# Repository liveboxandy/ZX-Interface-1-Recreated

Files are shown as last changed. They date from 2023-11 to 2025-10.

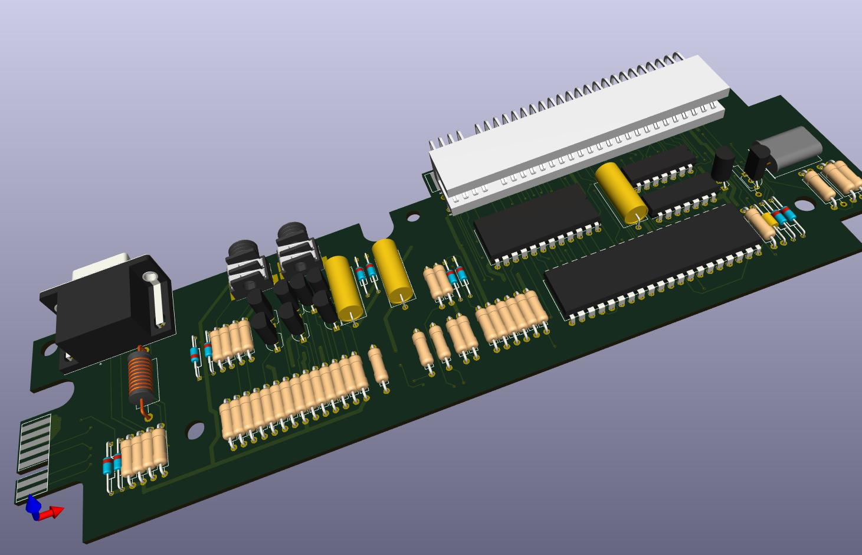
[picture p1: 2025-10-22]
Interface 1 Recreated.jpg

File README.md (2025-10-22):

# ZX-Interface-1-Recreated
Sinclair ZX Interface 1 recreated with the orignal Sinclair Routing

This is Kicad 9 project of the Sinclair ZX Interface 1 that uses the same routing and PCB dimensions as the orignal.
A raw board was scanned and the top and bottom side images were imported into Kicad. This gave the board outline 
along with the position of components and the track layout.
The schematic available from the Service Guide was then redrawn in Kicad and used to recreate the PCB and to verify that the routing was correct.

The Bill of Materials from the Service Guide was used to select suitable footprints. Some parts were obsolete and could not be located and so suitable repalcements were used.

Q11 does not have a place on the Sinclair PCB as it was an afterthought. To stop Kicad moaning I have placed it within the footprint of R2 which is not fitted.

This is the result of that exercise.

The files 'Interface 1 Recreated with images.*' when combined will produce an Interface 1 Recreated.kicad_pcb file that includes the top/bottom images. It appears that a 75MB is too be for uploading so I split it into 20MB chunks.

Sometimes Kicad complains that there is an issue with the edge.cuts file. Running DRC will show what it doesn't like and it's easy to fix so that the board outline is a closed shape.

The bom/ibom.html is an interactive BOM that will show component position as well as routing in a web browser.

Have fun.

Comments - Good Bad or totally indifferent on https://www.facebook.com/groups/zxspa/

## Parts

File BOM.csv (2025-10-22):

Reference | Value | Datasheet | Footprint | Qty | DNP
C1,C2,C6 | 47uF 16V | ~ | Capacitor_THT:C_Axial_L17.0mm_D6.5mm_P20.00mm_Horizontal | 3
C3 | 100pF | ~ | Spectrum:Capacitor Ceramic | 1
C4 | 22pF | ~ | Spectrum:Capacitor Ceramic | 1
C5 | 47nF | ~ | Capacitor_THT:C_Axial_L3.8mm_D2.6mm_P12.50mm_Horizontal | 1
C7,C8 | 330pF | ~ | Spectrum:Capacitor Ceramic | 2
D1,D2 | BA157 | https://www.vishay.com/docs/88536/ba157.pdf | Spectrum:Diode 1N | 2
D3,D4,D9,D10,D11 | 1N4148 | https://assets.nexperia.com/documents/data-sheet/1N4148_1N4448.pdf | Spectrum:Diode 1N | 5
D6,D7,D8 | BZX79CV4V3 | ~ | Spectrum:Diode 1N | 3
L1 | 22uH 0.41A | ~ | Inductor_THT:L_Axial_L12.8mm_D5.8mm_P20.32mm_Horizontal_Fastron_HBCC | 1
NoFit1 | 0R | ~ | Spectrum:Resistor_0.25W | 1 | DNP
Q1,Q2,Q4,Q5 | BC213C | ~ | Package_TO_SOT_THT:TO-92L_Inline_Wide | 4
Q3,Q6,Q9 | BC184C | ~ | Package_TO_SOT_THT:TO-92L_Inline_Wide | 3
Q10,Q11 | BC183 | ~ | Package_TO_SOT_THT:TO-92L_Inline_Wide | 2
R1,R3,R5,R11,R14,R19,R31 | 1K0 | -- mixed values -- | -- mixed values -- | 7
R2 | NoFit | ~ | Spectrum:Resistor_0.25W | 1 | DNP
R4,R6,R8,R16 | 3K9 | ~ | Spectrum:Resistor_0.25W | 4
R7 | 47R | ~ | Spectrum:Resistor_0.25W | 1
R9,R21,R25,R26,R27,R33,R36 | 10K | ~ | Spectrum:Resistor_0.25W | 7
R10 | 2K2 | ~ | Spectrum:Resistor_0.25W | 1
R12,R15 | 12K | ~ | Spectrum:Resistor_0.25W | 2
R13,R18,R32 | 680R | ~ | Spectrum:Resistor_0.25W | 3
R17,R20 | 2K7 | ~ | Spectrum:Resistor_0.25W | 2
R22,R23,R34 | 330R | ~ | Spectrum:Resistor_0.25W | 3
R24 | 4K7 | ~ | Spectrum:Resistor_0.25W | 1
R28,R29 | 6K8 | ~ | Spectrum:Resistor_0.25W | 2
R30 | 270R | ~ | Spectrum:Resistor_0.25W | 1
R35 | 47K | ~ | Spectrum:Resistor_0.25W | 1
SK1 | DE9_Receptacle | ~ | Connector_Dsub:DSUB-9_Female_Horizontal_P2.77x2.84mm_EdgePinOffset14.56mm_Housed_MountingHolesOffset15.98mm | 1
SK2,SK3 | Network | ~ | ZX Spectrum 3.5mm:ZX Spectrum 3.5mm Skt | 2
SK4 | Microdrive | ~ | ZX Bits:ZX_MD_Edge_Connector | 1
SK5 | ZX Spectrum |  | ZX Bits:Spectrum_Edge_Connector | 1
SK6 | ZX Expansion |  | ZX Bits:ZX_Bus_Edge_Connector | 1
U1 | LA15-302 | LA 15-302 Custom ULA | Package_DIP:DIP-40_W15.24mm | 1
U2 | TMS4764 |  | Package_DIP:DIP-24_W15.24mm | 1
U3 | 74LS260 |  | Package_DIP:DIP-14_W7.62mm | 1
U4 | 74HC04 | https://assets.nexperia.com/documents/data-sheet/74HC_HCT04.pdf | Package_DIP:DIP-14_W7.62mm | 1
X1 | 8Mhz | ~ | Crystal:Crystal_HC18-U_Horizontal | 1

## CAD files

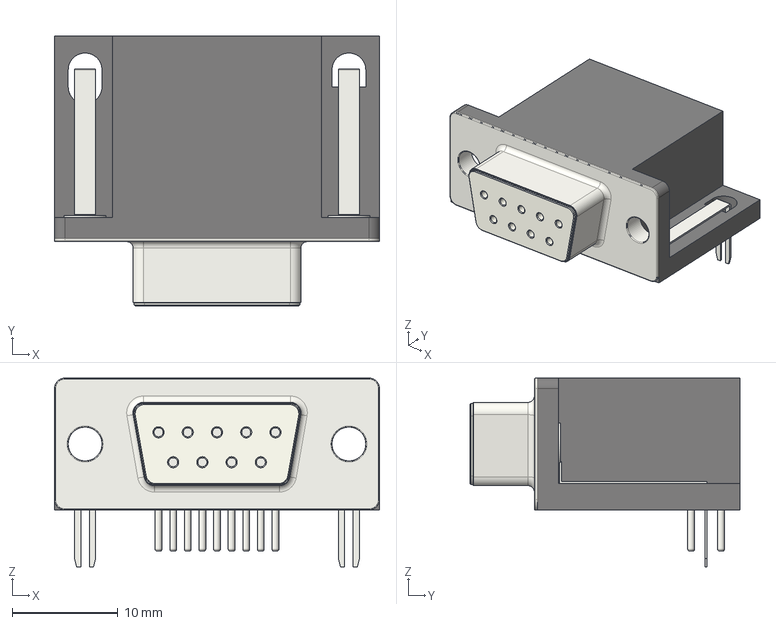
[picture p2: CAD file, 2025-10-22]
Step/DSUB-9_Female_Horizontal_P2.77x2.84mm_EdgePinOffset14.56mm_Housed_MountingHolesOffset15.98mm.step
30.8 x 25.6 x 17.9 mm

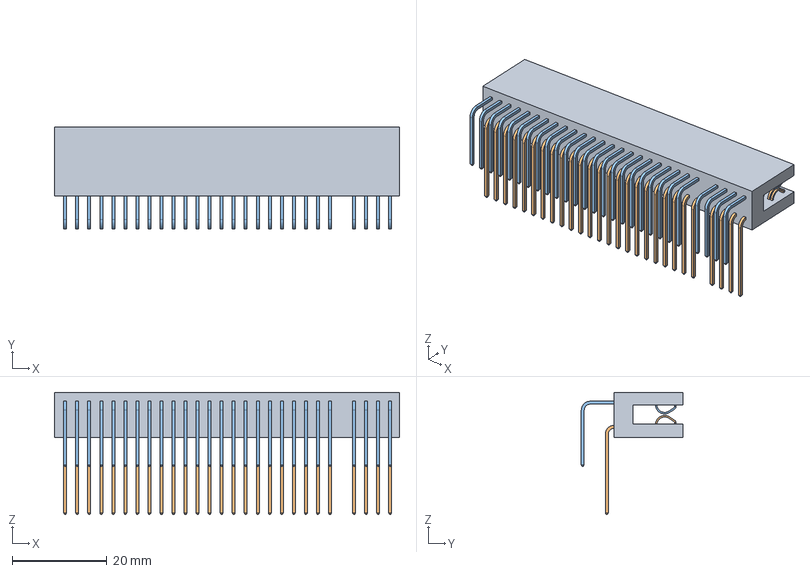
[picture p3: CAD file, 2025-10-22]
Step/28+28 RA ZX Spectrum.step
72.8 x 21.4 x 25.8 mm
345-292-001_558 559 Tail - 1
345-292-001_558 Tail - 2
345-292-001_558 559 Tail - 002
345-292-001_558 559 Tail - 003
345-292-001_558 Tail - 003
345-292-001_558 Tail - 004
345-292-001_558 559 Tail - 004
345-292-001_558 559 Tail - 005
345-292-001_558 Tail - 005
345-292-001_558 Tail - 006
345-292-001_558 559 Tail - 006
345-292-001_558 Tail - 007
345-292-001_558 559 Tail - 007
345-292-001_558 Tail - 008
345-292-001_558 559 Tail - 008
345-292-001_558 Tail - 009
345-292-001_558 559 Tail - 009
345-292-001_558 Tail - 010
345-292-001_558 559 Tail - 010
345-292-001_558 Tail - 011
345-292-001_558 559 Tail - 011
345-292-001_558 Tail - 012
345-292-001_558 559 Tail - 012
345-292-001_558 Tail - 013
345-292-001_558 559 Tail - 013
345-292-001_558 Tail - 014
345-292-001_558 559 Tail - 014
345-292-001_558 Tail - 015
345-292-001_558 559 Tail - 015
345-292-001_558 Tail - 016
345-292-001_558 559 Tail - 016
345-292-001_558 Tail - 017
345-292-001_558 559 Tail - 017
345-292-001_558 Tail - 018
345-292-001_558 559 Tail - 018
345-292-001_558 Tail - 019
345-292-001_558 559 Tail - 019
345-292-001_558 Tail - 020
345-292-001_558 559 Tail - 020
345-292-001_558 Tail - 021
345-292-001_558 559 Tail - 021
345-292-001_558 Tail - 022
345-292-001_558 559 Tail - 022
345-292-001_558 Tail - 023
345-292-001_558 559 Tail - 023
345-292-001_558 Tail - 024
345-292-001_558 559 Tail - 025
345-292-001_558 Tail - 026
345-292-001_558 559 Tail - 026
345-292-001_558 Tail - 027
345-292-001_558 559 Tail - 027
345-292-001_558 Tail - 028
345-292-001_558 559 Tail - 028
345-292-001_558 Tail - 029

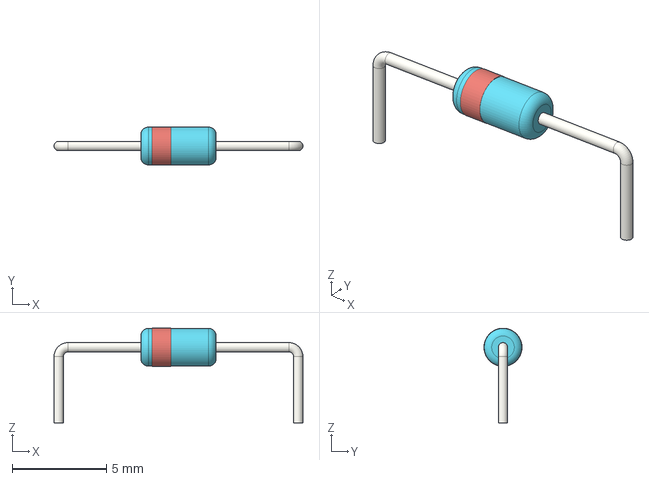
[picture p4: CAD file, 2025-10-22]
Step/D_DO-35_SOD27_P12.70mm_Horizontal.step
13.2 x 2.02 x 5.01 mm

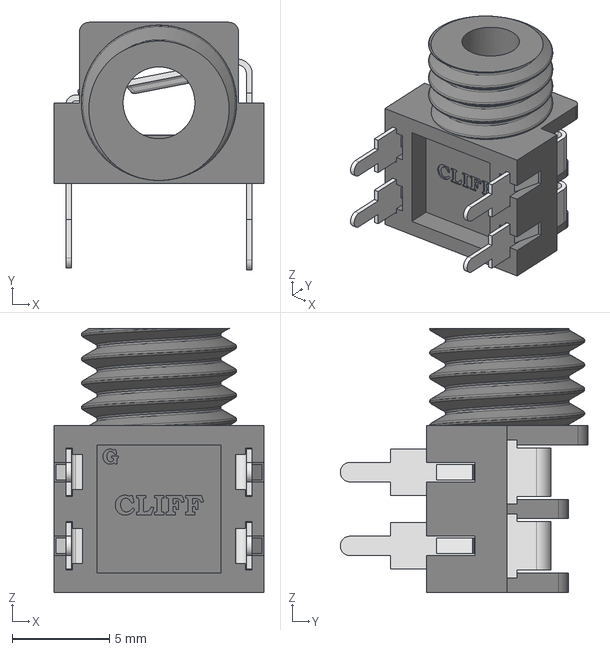
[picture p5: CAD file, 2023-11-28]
Step/FCR1281 S6A 6mm.stp
10.8 x 12.8 x 13.6 mm

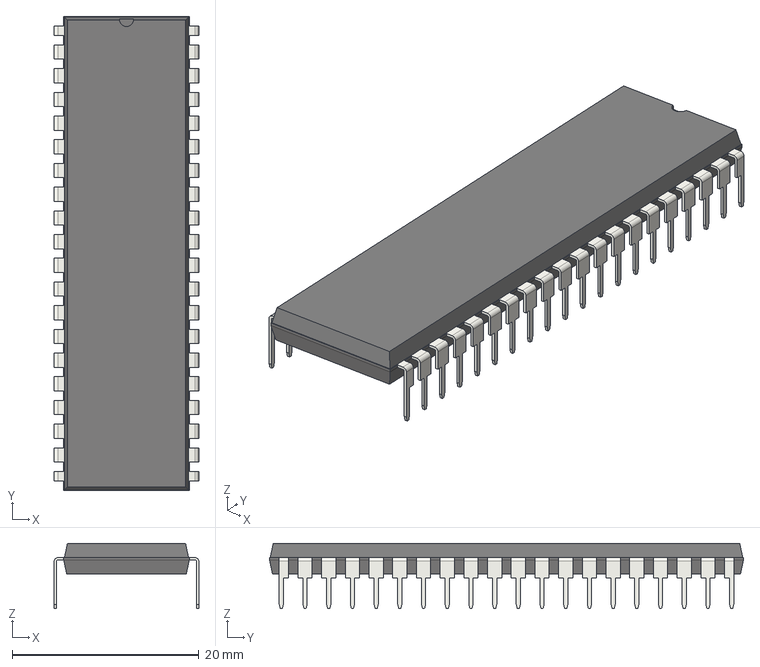
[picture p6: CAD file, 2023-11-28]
Step/DIP-40_W15.24mm.step
15.5 x 50.8 x 6.98 mm

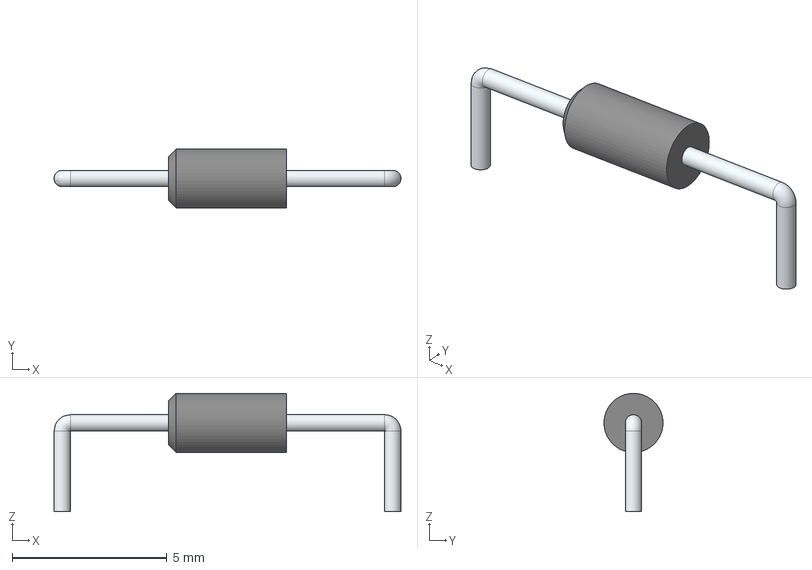
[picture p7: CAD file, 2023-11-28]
Step/1N4148.stp
11.2 x 1.91 x 3.82 mm

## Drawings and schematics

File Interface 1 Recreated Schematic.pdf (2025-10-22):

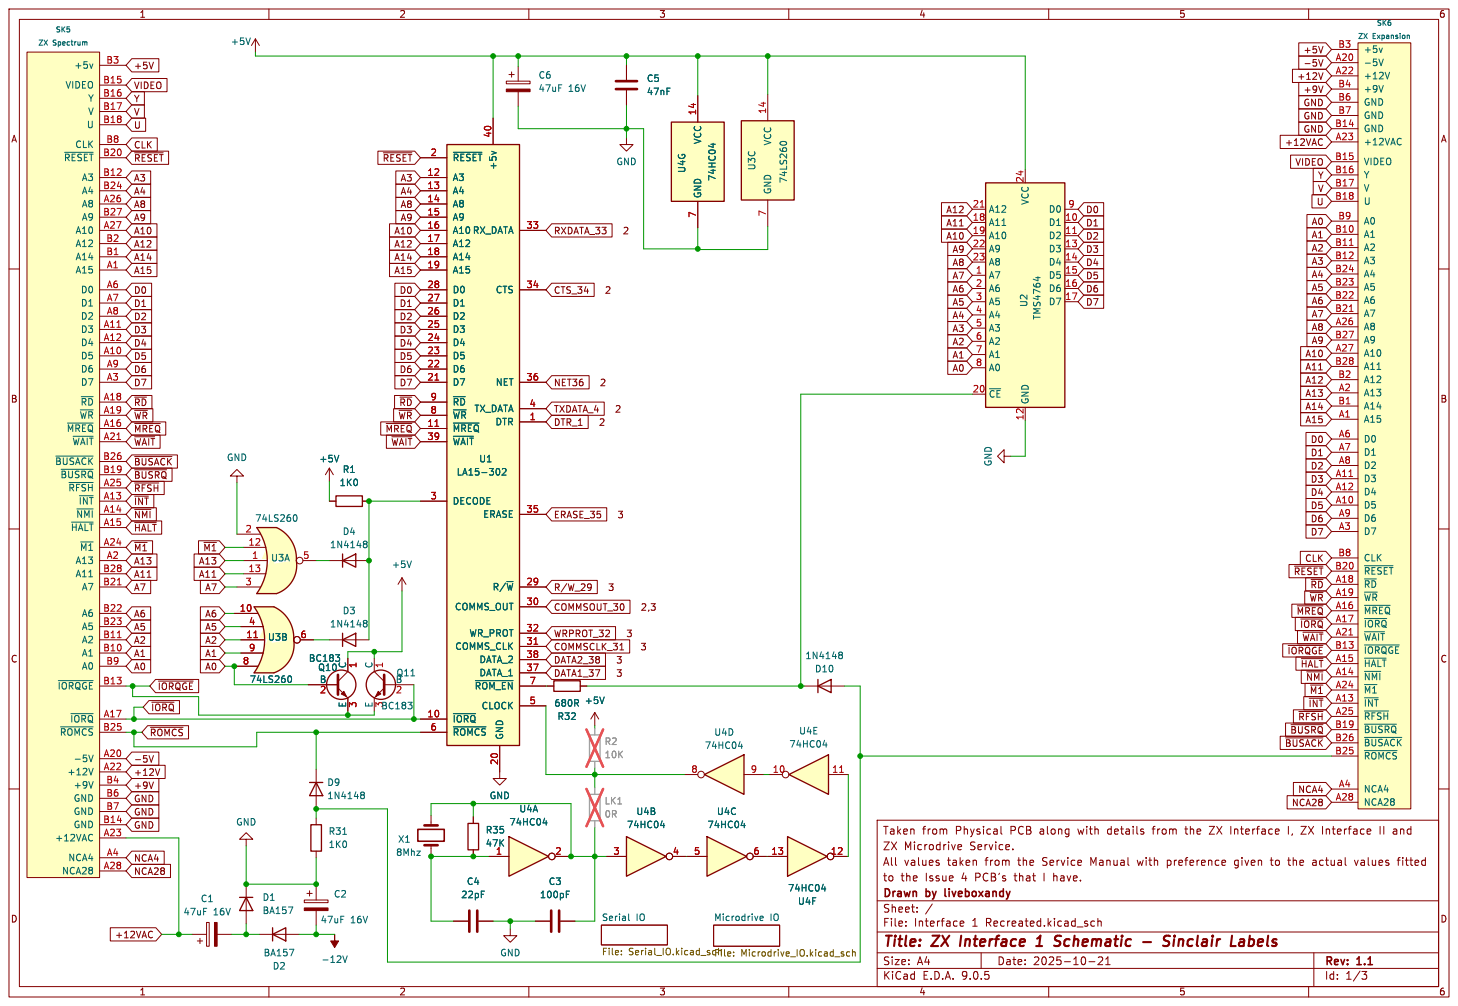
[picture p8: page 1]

Id: 1/3 Title: ZX Interface 1 Schematic - Sinclair Labels

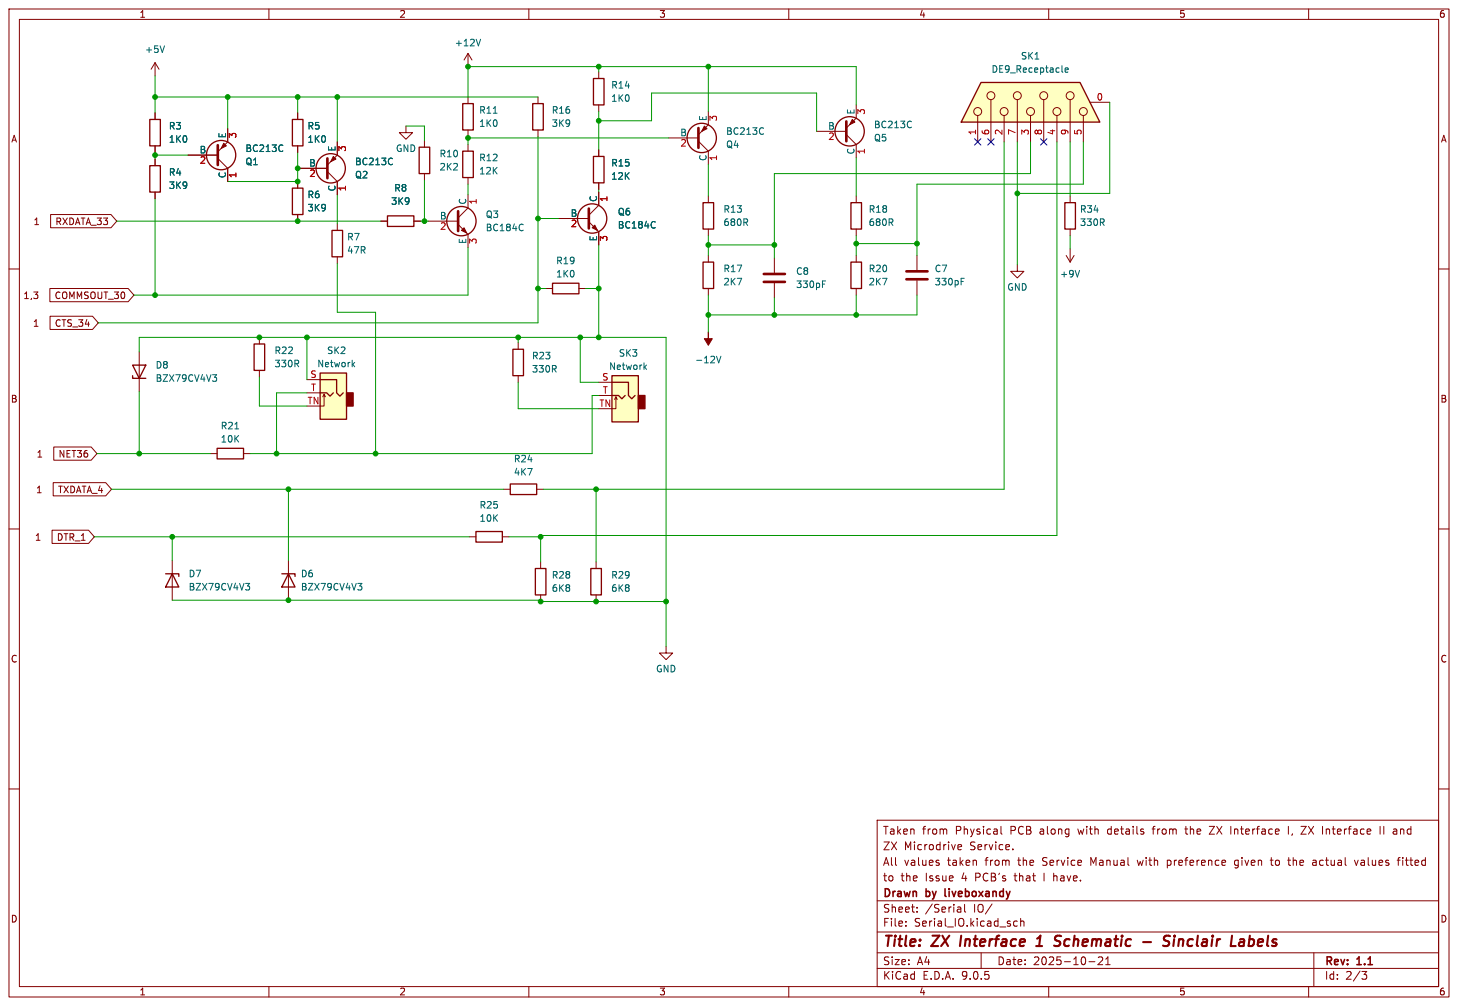
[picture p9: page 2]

Id: 2/3 Title: ZX Interface 1 Schematic - Sinclair Labels

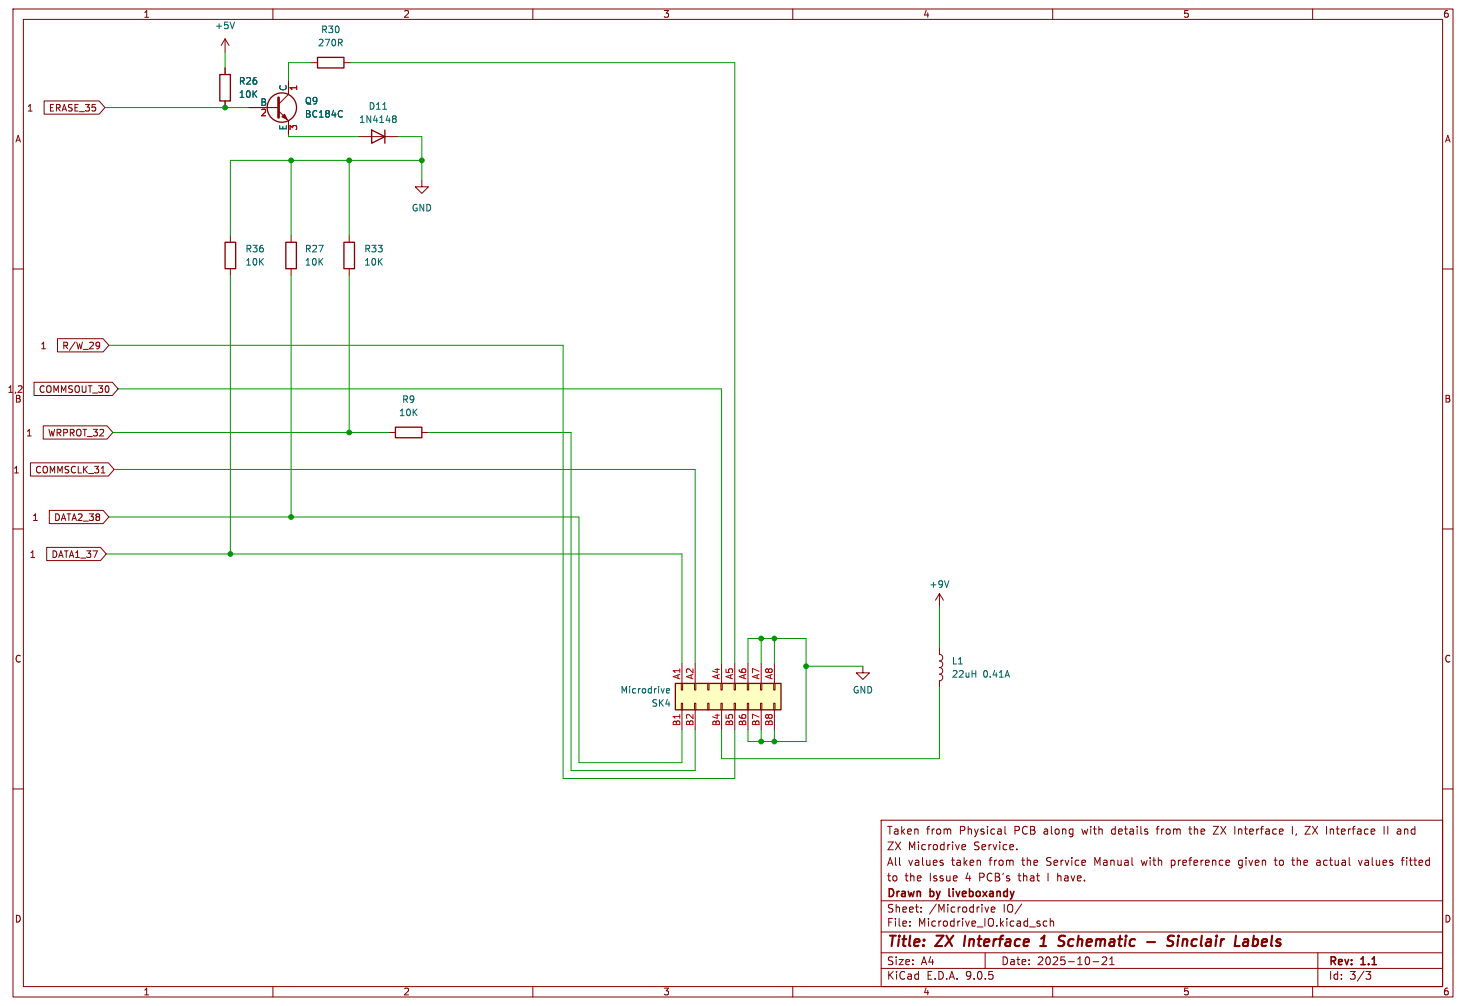
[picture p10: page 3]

Id: 3/3 Title: ZX Interface 1 Schematic - Sinclair Labels

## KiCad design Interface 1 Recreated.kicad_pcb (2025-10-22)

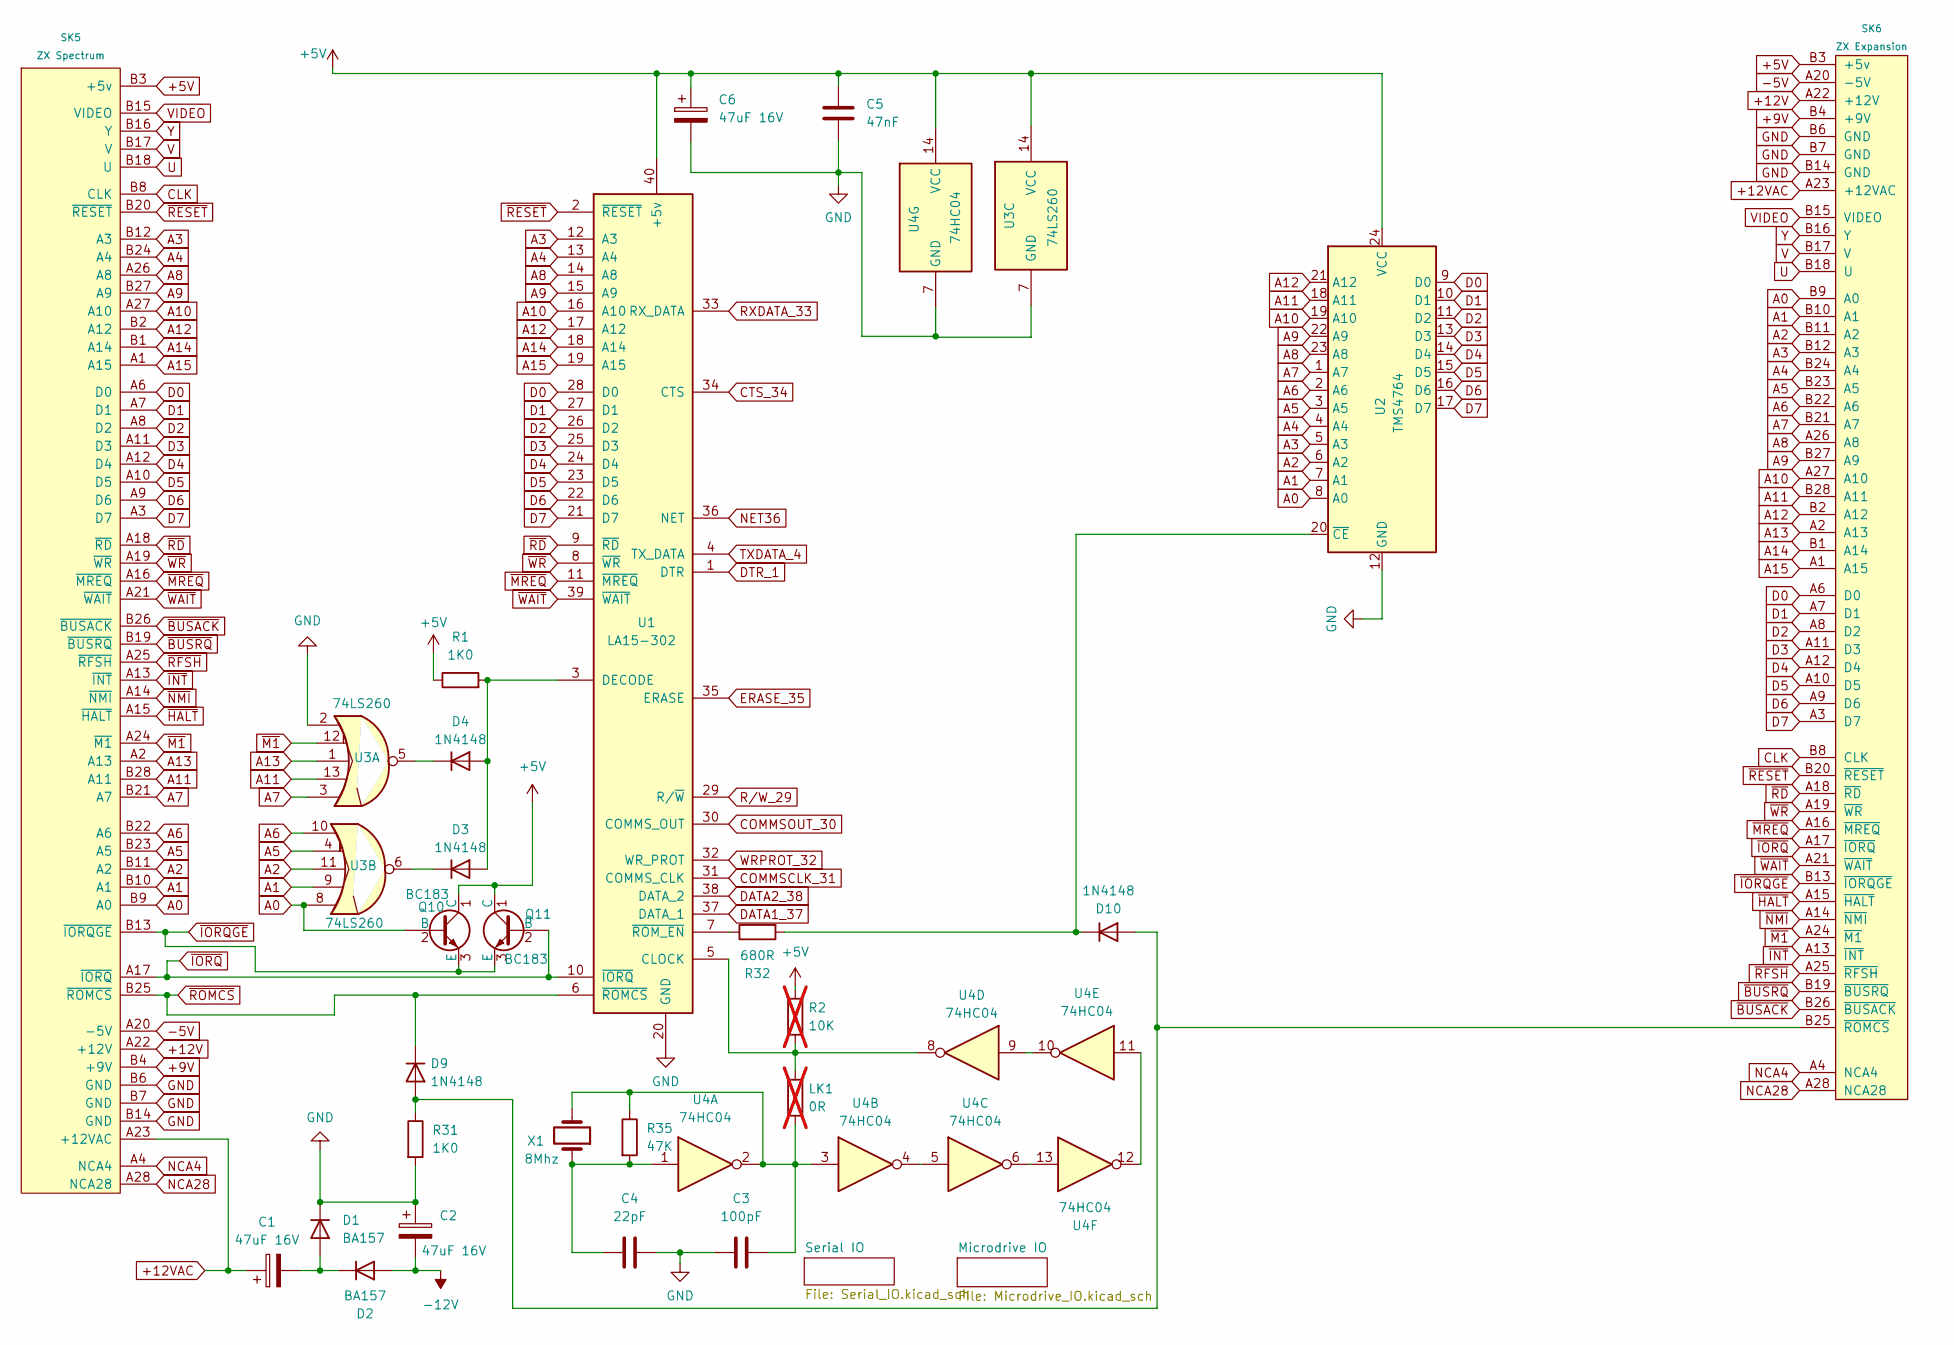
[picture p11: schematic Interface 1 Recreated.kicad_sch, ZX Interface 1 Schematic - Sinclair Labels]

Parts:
C1, C2, C6: 47uF 16V; C_Axial_L17.0mm_D6.5mm_P20.00mm_Horizontal
C3: 100pF; Capacitor Ceramic
C4: 22pF; Capacitor Ceramic
C5: 47nF; C_Axial_L3.8mm_D2.6mm_P12.50mm_Horizontal
D1, D2: BA157; Diode 1N
D3, D4, D9, D10: 1N4148; Diode 1N
LK1: 0R; Resistor_0.25W; not fitted
Q10, Q11: BC183; TO-92L_Inline_Wide
R1, R31: 1K0; Resistor_0.25W
R2: 10K; Resistor_0.25W; not fitted
R32: 680R; Resistor_0.25W
R35: 47K; Resistor_0.25W
SK5: ZX Spectrum; Edge_Connector_Up_To_Spectrum
SK6: ZX Expansion; Edge_Connector_To_AddOn
U1: LA15-302; DIP-40_W15.24mm
U2: TMS4764; DIP-24_W15.24mm
U3: 74LS260; DIP-14_W7.62mm
U4: 74HC04; DIP-14_W7.62mm
X1: 8Mhz; Crystal_HC18-U_Horizontal

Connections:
+5V: C5.1, C6.1, Q10.1 (C), Q11.1 (C), R1.1, R2.1, SK5.B3 (+5v), SK6.B3 (+5v), U1.40 (+5v), U2.24 (VCC), U3.14 (VCC), U4.14 (VCC); also elsewhere on the board
+9V: SK5.B4 (+9V), SK6.B4 (+9V); also elsewhere on the board
+12V: SK5.A22 (+12V), SK6.A22 (+12V); also elsewhere on the board
+12VAC: C1.1, SK5.A23 (+12VAC), SK6.A23 (+12VAC)
-5V: SK5.A20 (-5V), SK6.A20 (-5V)
-12V: C2.2, D2.2 (A); also elsewhere on the board
A0: Q10.2 (B), SK5.B9 (A0), SK6.B9 (A0), U2.8 (A0), U3.8
A1: SK5.B10 (A1), SK6.B10 (A1), U2.7 (A1), U3.9
A2: SK5.B11 (A2), SK6.B11 (A2), U2.6 (A2), U3.11
A3: SK5.B12 (A3), SK6.B12 (A3), U1.12 (A3), U2.5 (A3)
A4: SK5.B24 (A4), SK6.B24 (A4), U1.13 (A4), U2.4 (A4)
A5: SK5.B23 (A5), SK6.B23 (A5), U2.3 (A5), U3.4
A6: SK5.B22 (A6), SK6.B22 (A6), U2.2 (A6), U3.10
A7: SK5.B21 (A7), SK6.B21 (A7), U2.1 (A7), U3.3
A8: SK5.A26 (A8), SK6.A26 (A8), U1.14 (A8), U2.23 (A8)
A9: SK5.B27 (A9), SK6.B27 (A9), U1.15 (A9), U2.22 (A9)
A10: SK5.A27 (A10), SK6.A27 (A10), U1.16 (A10), U2.19 (A10)
A11: SK5.B28 (A11), SK6.B28 (A11), U2.18 (A11), U3.13
A12: SK5.B2 (A12), SK6.B2 (A12), U1.17 (A12), U2.21 (A12)
A13: SK5.A2 (A13), SK6.A2 (A13), U3.1
A14: SK5.B1 (A14), SK6.B1 (A14), U1.18 (A14)
A15: SK5.A1 (A15), SK6.A1 (A15), U1.19 (A15)
CLK: SK5.B8 (CLK), SK6.B8 (CLK)
COMMSCLK_31: U1.31 (COMMS_CLK); also elsewhere on the board
COMMSOUT_30: U1.30 (COMMS_OUT); also elsewhere on the board
CTS_34: U1.34 (CTS); also elsewhere on the board
D0: SK5.A6 (D0), SK6.A6 (D0), U1.28 (D0), U2.9 (D0)
D1: SK5.A7 (D1), SK6.A7 (D1), U1.27 (D1), U2.10 (D1)
D2: SK5.A8 (D2), SK6.A8 (D2), U1.26 (D2), U2.11 (D2)
D3: SK5.A11 (D3), SK6.A11 (D3), U1.25 (D3), U2.13 (D3)
D4: SK5.A12 (D4), SK6.A12 (D4), U1.24 (D4), U2.14 (D4)
D5: SK5.A10 (D5), SK6.A10 (D5), U1.23 (D5), U2.15 (D5)
D6: SK5.A9 (D6), SK6.A9 (D6), U1.22 (D6), U2.16 (D6)
D7: SK5.A3 (D7), SK6.A3 (D7), U1.21 (D7), U2.17 (D7)
DATA1_37: U1.37 (DATA_1); also elsewhere on the board
DATA2_38: U1.38 (DATA_2); also elsewhere on the board
DTR_1: U1.1 (DTR); also elsewhere on the board
ERASE_35: U1.35 (ERASE); also elsewhere on the board
GND: C2.1, C3.2, C4.1, C5.2, C6.2, D1.1 (K), R31.2, SK5.B6 (GND), SK5.B7 (GND), SK5.B14 (GND), SK6.B6 (GND), SK6.B7 (GND), SK6.B14 (GND), U1.20 (GND), U2.12 (GND), U3.2, U3.7 (GND), U4.7 (GND); also elsewhere on the board
NCA4: SK5.A4 (NCA4), SK6.A4 (NCA4)
NCA28: SK5.A28 (NCA28), SK6.A28 (NCA28)
NET36: U1.36 (NET); also elsewhere on the board
unnamed: C3.1, LK1.2, R35.1, U4.2, U4.3, X1.2
unnamed: C4.2, R35.2, U4.1, X1.1
unnamed: C1.2, D1.2 (A), D2.1 (K)
unnamed: D3.2 (A), D4.2 (A), R1.2, U1.3 (DECODE)
unnamed: D3.1 (K), U3.6
unnamed: D4.1 (K), U3.5
unnamed: D9.2 (A), D10.2 (A), R31.1, SK6.B25 (~ROMCS)
unnamed: D10.1 (K), R32.2, U2.20 (~CE)
unnamed: LK1.1, R2.2, U1.5 (CLOCK), U4.8
unnamed: R32.1, U1.7 (~ROM_EN)
unnamed: U4.4, U4.5
unnamed: U4.9, U4.10
unnamed: U4.11, U4.12
unnamed: U4.6, U4.13
RXDATA_33: U1.33 (RX_DATA); also elsewhere on the board
R/W_29: U1.29 (R/~W); also elsewhere on the board
TXDATA_4: U1.4 (TX_DATA); also elsewhere on the board
U: SK5.B18 (U), SK6.B18 (U)
V: SK5.B17 (V), SK6.B17 (V)
VIDEO: SK5.B15 (VIDEO), SK6.B15 (VIDEO)
WRPROT_32: U1.32 (WR_PROT); also elsewhere on the board
Y: SK5.B16 (Y), SK6.B16 (Y)
~BUSACK: SK5.B26 (~BUSACK), SK6.B26 (~BUSACK)
~BUSRQ: SK5.B19 (~BUSRQ), SK6.B19 (~BUSRQ)
~HALT: SK5.A15 (~HALT), SK6.A15 (~HALT)
~INT: SK5.A13 (~INT), SK6.A13 (~INT)
~IORQGE: Q10.3 (E), Q11.3 (E), SK5.B13 (~IORQGE), SK6.B13 (~IORQGE)
~IORQ: Q11.2 (B), SK5.A17 (~IORQ), SK6.A17 (~IORQ), U1.10 (~IORQ)
~M1: SK5.A24 (~M1), SK6.A24 (~M1), U3.12
~MREQ: SK5.A16 (~MREQ), SK6.A16 (~MREQ), U1.11 (~MREQ)
~NMI: SK5.A14 (~NMI), SK6.A14 (~NMI)
~RD: SK5.A18 (~RD), SK6.A18 (~RD), U1.9 (~RD)
~RESET: SK5.B20 (~RESET), SK6.B20 (~RESET), U1.2 (~RESET)
~RFSH: SK5.A25 (~RFSH), SK6.A25 (~RFSH)
~ROMCS: D9.1 (K), SK5.B25 (~ROMCS), U1.6 (~ROMCS)
~WAIT: SK5.A21 (~WAIT), SK6.A21 (~WAIT), U1.39 (~WAIT)
~WR: SK5.A19 (~WR), SK6.A19 (~WR), U1.8 (~WR)

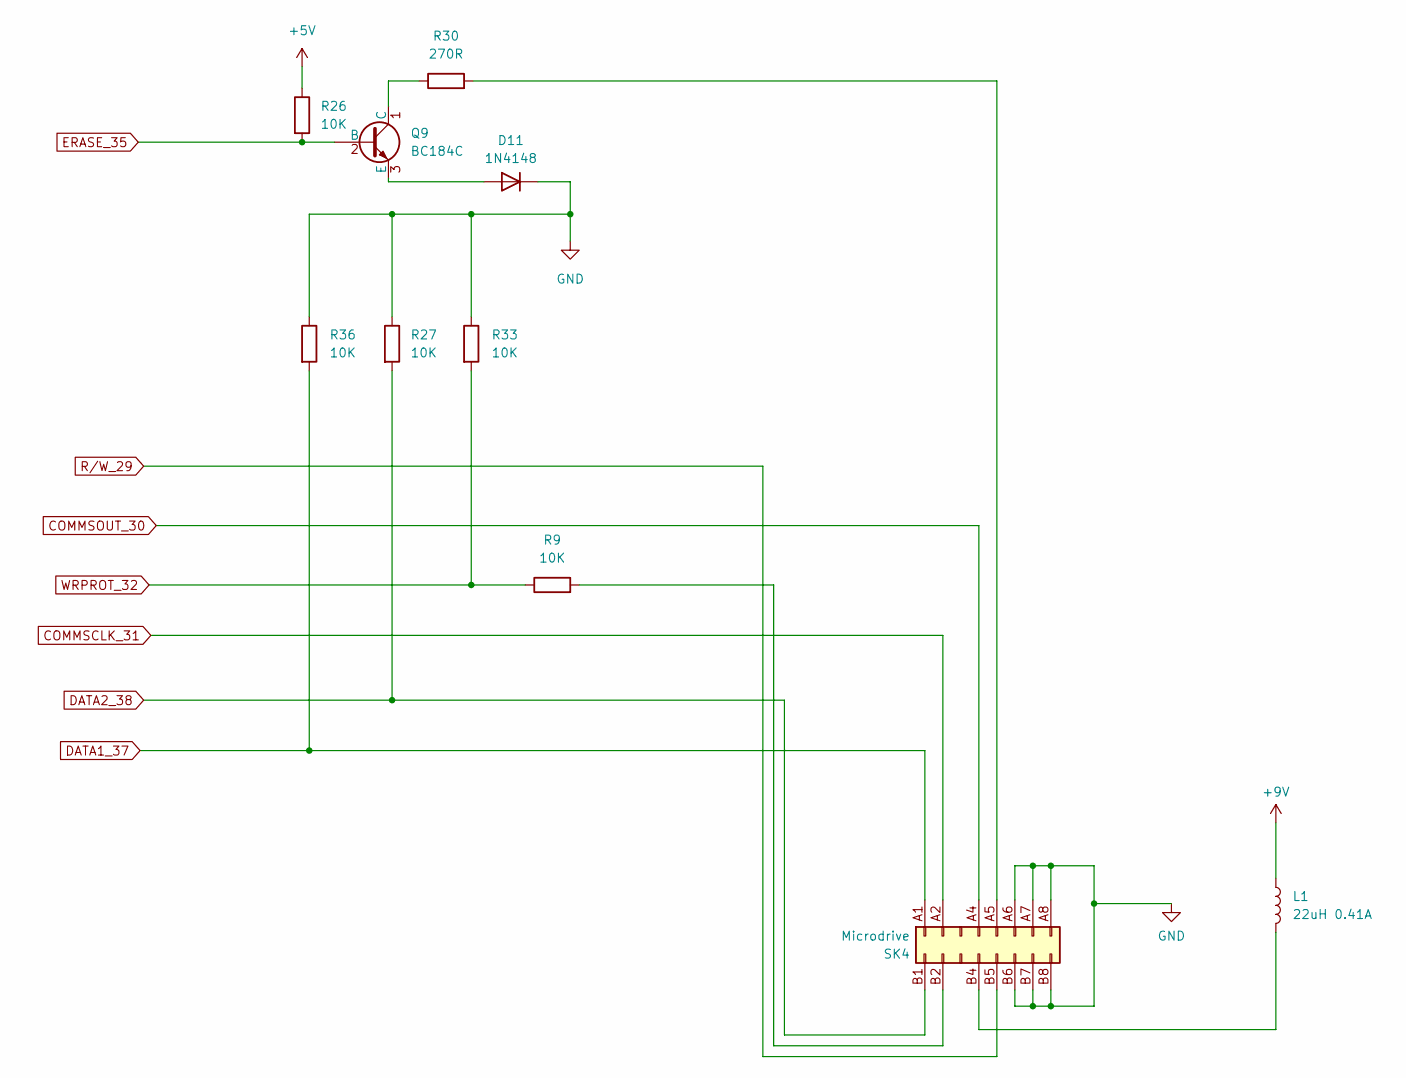
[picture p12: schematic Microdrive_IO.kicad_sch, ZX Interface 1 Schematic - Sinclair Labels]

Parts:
D11: 1N4148; Diode 1N
L1: 22uH 0.41A; L_Axial_L12.8mm_D5.8mm_P20.32mm_Horizontal_Fastron_HBCC
Q9: BC184C; TO-92L_Inline_Wide
R9, R26, R27, R33, R36: 10K; Resistor_0.25W
R30: 270R; Resistor_0.25W
SK4: Microdrive; ZX_MD_Edge_Connector

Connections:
+5V: R26.1; also elsewhere on the board
+9V: L1.1; also elsewhere on the board
COMMSCLK_31: SK4.A2; also elsewhere on the board
COMMSOUT_30: SK4.A4; also elsewhere on the board
DATA1_37: R36.2, SK4.A1; also elsewhere on the board
DATA2_38: R27.2, SK4.B1; also elsewhere on the board
ERASE_35: Q9.2 (B), R26.2; also elsewhere on the board
GND: D11.1 (K), R27.1, R33.1, R36.1, SK4.A6, SK4.A7, SK4.A8, SK4.B6, SK4.B7, SK4.B8; also elsewhere on the board
unnamed: D11.2 (A), Q9.3 (E)
unnamed: Q9.1 (C), R30.1
unnamed: R30.2, SK4.A5
unnamed: R9.2, SK4.B2
unnamed: L1.2, SK4.B4
R/W_29: SK4.B5; also elsewhere on the board
WRPROT_32: R9.1, R33.2; also elsewhere on the board

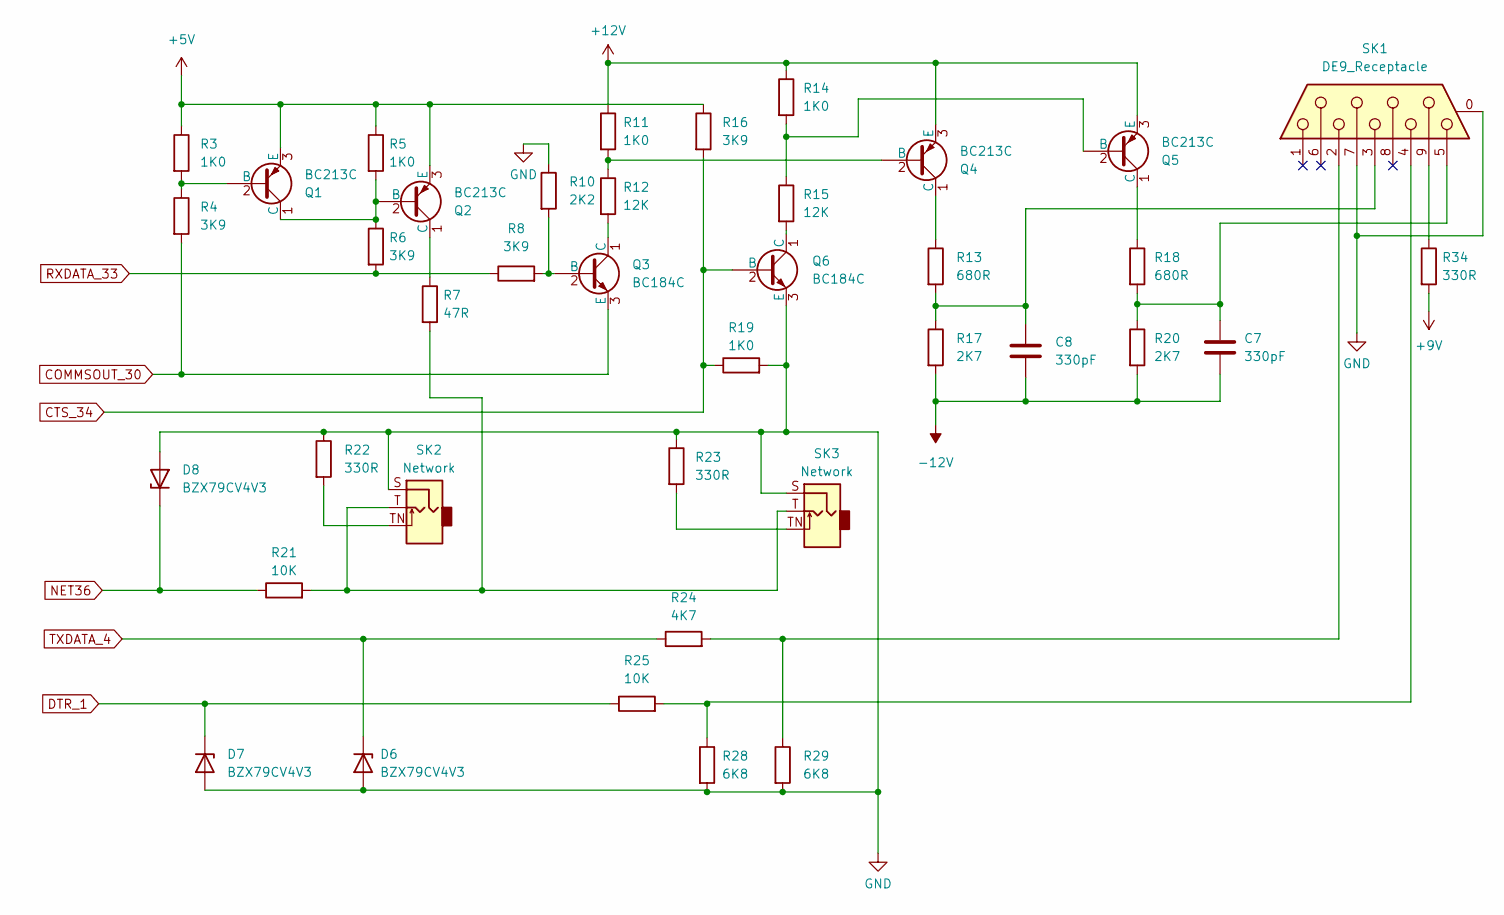
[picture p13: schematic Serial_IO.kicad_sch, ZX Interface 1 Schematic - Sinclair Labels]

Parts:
C7, C8: 330pF; Capacitor Ceramic
D6, D7, D8: BZX79CV4V3; Diode 1N
Q1, Q2, Q4, Q5: BC213C; TO-92L_Inline_Wide
Q3, Q6: BC184C; TO-92L_Inline_Wide
R3, R5, R11, R14, R19: 1K0; Resistor_0.25W
R4, R6, R8, R16: 3K9; Resistor_0.25W
R7: 47R; Resistor_0.25W
R10: 2K2; Resistor_0.25W
R12, R15: 12K; Resistor_0.25W
R13, R18: 680R; Resistor_0.25W
R17, R20: 2K7; Resistor_0.25W
R21, R25: 10K; Resistor_0.25W
R22, R23, R34: 330R; Resistor_0.25W
R24: 4K7; Resistor_0.25W
R28, R29: 6K8; Resistor_0.25W
SK1: DE9_Receptacle; DSUB-9_Female_Horizontal_P2.77x2.84mm_EdgePinOffset14.56mm_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
SK2, SK3: Network; ZX Spectrum 3.5mm Skt

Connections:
+5V: Q1.3 (E), Q2.3 (E), R3.1, R5.1, R16.1; also elsewhere on the board
+9V: R34.2; also elsewhere on the board
+12V: Q4.3 (E), Q5.3 (E), R11.1, R14.1; also elsewhere on the board
-12V: C7.2, C8.2, R17.2, R20.2; also elsewhere on the board
COMMSOUT_30: Q3.3 (E), R4.2; also elsewhere on the board
CTS_34: Q6.2 (B), R16.2, R19.1; also elsewhere on the board
DTR_1: D7.1 (K), R25.1; also elsewhere on the board
GND: D6.2 (A), D7.2 (A), D8.2 (A), Q6.3 (E), R10.1, R19.2, R22.1, R23.1, R28.2, R29.2, SK1.0 (PAD), SK1.7, SK2.S, SK3.S; also elsewhere on the board
NET36: D8.1 (K), R21.1; also elsewhere on the board
unnamed: C7.1, R18.2, R20.1, SK1.5
unnamed: C8.1, R13.2, R17.1, SK1.3
unnamed: Q1.2 (B), R3.2, R4.1
unnamed: Q1.1 (C), Q2.2 (B), R5.2, R6.1
unnamed: Q2.1 (C), R7.1
unnamed: Q3.2 (B), R8.2, R10.2
unnamed: Q3.1 (C), R12.2
unnamed: Q4.2 (B), R11.2, R12.1
unnamed: Q4.1 (C), R13.1
unnamed: Q5.2 (B), R14.2, R15.1
unnamed: Q5.1 (C), R18.1
unnamed: Q6.1 (C), R15.2
unnamed: R7.2, R21.2, SK2.T, SK3.T
unnamed: R22.2, SK2.TN
unnamed: R23.2, SK3.TN
unnamed: R24.2, R29.1, SK1.2
unnamed: R25.2, R28.1, SK1.4
unnamed: R34.1, SK1.9
RXDATA_33: R6.2, R8.1; also elsewhere on the board
TXDATA_4: D6.1 (K), R24.1; also elsewhere on the board

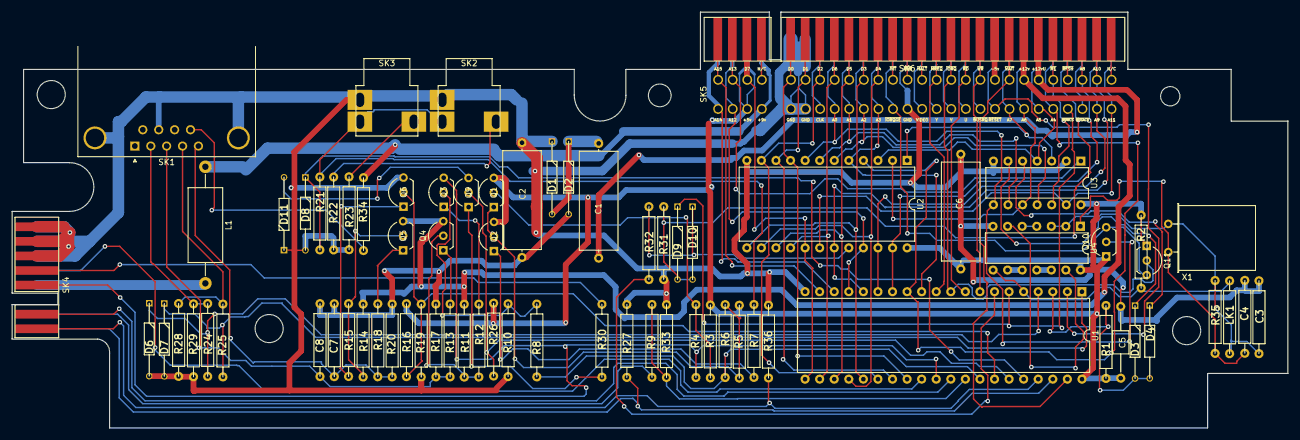
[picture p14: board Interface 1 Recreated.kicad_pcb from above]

Board: 2 copper layers, 222.4 x 72.5 mm, 76 parts (0 on the bottom side), 102 nets.

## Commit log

2025-10-22 Add files via upload
    Updated with Kicad 9. Now includes bom/ibom.html (Interactice BOM)
    [1N4148.stp, 28+28 RA ZX Spectrum.step, BOM.csv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]
2025-10-22 Add files via upload
    kicad.pcb with images of original PCB Part 1
2025-10-22 Add files via upload
    kicad.pcb with images of original PCB Part 2
2025-10-22 Add files via upload
    kicad.pcb with images of original PCB Part 3
2025-10-22 Add files via upload
    kicad.pcb with images of original PCB Part 4

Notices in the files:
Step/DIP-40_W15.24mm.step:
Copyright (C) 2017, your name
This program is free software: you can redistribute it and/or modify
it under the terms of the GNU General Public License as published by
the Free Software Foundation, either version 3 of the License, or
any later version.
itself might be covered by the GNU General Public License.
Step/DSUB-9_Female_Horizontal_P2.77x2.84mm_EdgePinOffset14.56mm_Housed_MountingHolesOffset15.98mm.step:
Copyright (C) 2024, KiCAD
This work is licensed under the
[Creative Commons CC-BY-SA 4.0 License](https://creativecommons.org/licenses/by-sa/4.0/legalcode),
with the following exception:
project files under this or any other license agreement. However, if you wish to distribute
